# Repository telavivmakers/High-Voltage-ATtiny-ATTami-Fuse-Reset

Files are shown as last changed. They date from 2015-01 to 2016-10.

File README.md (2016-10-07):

## High-Voltage-ATtiny-ATTami-Fuse-Reset

Based on Wayne Holder work "ATTiny Fuse Reset with 12 Volt Charge Pump" from 2010 [link](https://sites.google.com/site/wayneholder/attiny-fuse-reset-with-12-volt-charge-pump) 

With some changes:
* The collector of the Q1 transistor in Waynes diagram shorted D4 to ground via the 4 diods D1, D2, D3 and D4. Even though no harm is expected since the Arduino port pin is short circuit protected it is neater to prevent the short circuit. I moved the collector so it is connected via 1Kohm resistor.
* I changed some of the names in the schematic diagram and in the code to better depict their function.

The circuit will be build as Arduino shield with the following sockets:
* 8 pin DIP socket for 8 pin ATTiny13, ATTiny25, ATTiny45 or ATTiny85 fuse reseting/programming.
* 14 pin DIP socket for 14 pin ATTiny24, ATTiny44 or ATTiny84 fuse reseting/programming.
* Headers and POGO-PIN fixture for reseting/programming [ATTami](https://github.com/telavivmakers/at-tami) boards.

###Schema
[PDF](https://github.com/telavivmakers/High-Voltage-ATtiny-ATTami-Fuse-Reset/raw/master/ATTiny%20Fuse%20Reset%20with%2012V%20Charge%20Pump-schema.pdf)

###Layout
using topoR and some manual work


###BOM 
(Bill_of_materials)
[goog spreadsheet](https://docs.google.com/spreadsheets/d/1eC7mB2Z6gQL06fDRTFxQvt10aQQUTHuxl4aS4G3XxKg/edit?usp=sharing)

###todo
* TARGET/ ISP VCC switch must die
*

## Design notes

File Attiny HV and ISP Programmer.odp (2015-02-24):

## Attiny HV and ISP Programmer

Developed at TAMI

Tel-Aviv Makers International

## Project goals

- Main goal
  - High Voltage fuse reset of ATTami boards.
- By products:
  - High Voltage fuse reset of Attiny components.
  - ISP programming of ATTami boards.
  - ISP programming of Attiny components.
  - ISP programming of various AVR based boards, under either 5V or 3.3V supply.
  - Acceptance test of ATTami boards.
  - Self contained ATTami bootloader loading (Not yet implemented)

ATTami HV and ISP Programmer

2/24/2015

## Project structure

- Arduino shield with the following features:
  - Charge pump circuit to provide the 11.5V for the HV programming.
  - Bi directional 5V to 3.3V level shifters.
  - Sockets to enable programming of ATTami boards and Attiny components.
  - Indicator LEDs.
  - ATTami ATP LEDs.
  - Control switches.

ATTami HV and ISP Programmer

2/24/2015

## Charge pump circuit

- Charge pump is a circuit that produces high voltage by switching of capacitors.
- See: http://en.wikipedia.org/wiki/Charge_pump
- In our case we produce 11.5V out of the Arduino 5V supply.
- The 11.5V is controlled and regulated by the Arduino.

ATTami HV and ISP Programmer

2/24/2015

## Bi directional 5V to 3.3V level shifters

- 4 MOSFET based bi-directional level shifters to shift the 5V Arduino I/O pins level to 3.3V.
- See: http://delphys.net/d.holmes/hardware/levelshift.html

ATTami HV and ISP Programmer

2/24/2015

## Sockets to enable programming of ATTami boards and Attiny components

  - Pogo-Pins socket to enable programming and testing of pinless ATTami boards.
  - Sockets to enable programming and testing of ATTami boards with upper or lower pins.
  - Socket for 8 pin ATtiny programming.
  - Socket for 14 pin ATtiny programming.
  - Socket for 6 pin ISP ribbon.
  - Socket for 10 pin ISP ribbon.

ATTami HV and ISP Programmer

2/24/2015

## Control Switches

- ISP – HV selector: Selects witch programming mode will be performed
- 3.3V – 5V selector: Selects the I/O pins level to conform with the external board connected to the ISP cables.
- ISP Vcc – Target Vcc selector: Selects if The programmer will provide Vcc to the target board via the ISP cables.
- ATTami test pushbutton: Provides Vcc to the ATTami board.
- ATTami load bootloader: Initiate loading to the ATTami of the bootloader Hex file stored on the Arduino Flash memory. (This function is not yet implemented.)

ATTami HV and ISP Programmer

2/24/2015

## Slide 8

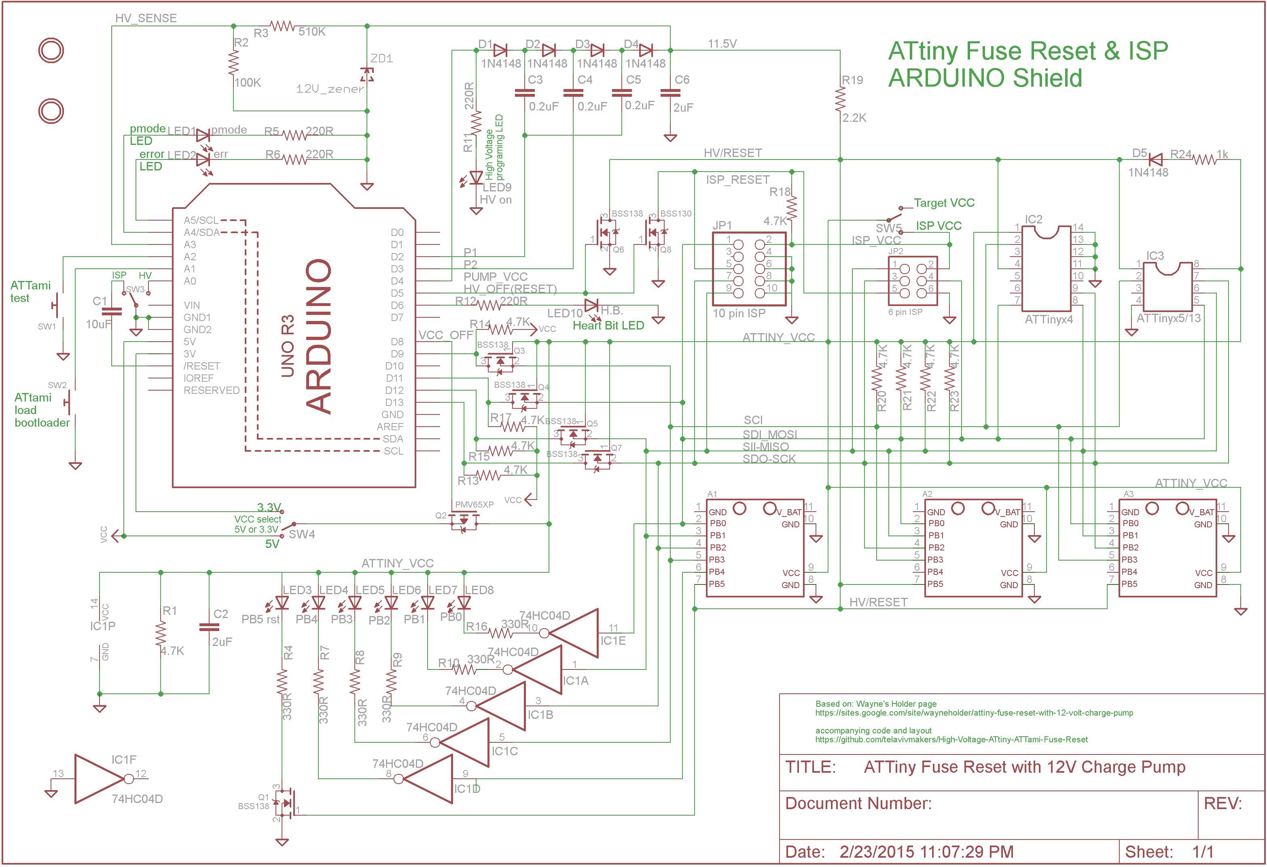
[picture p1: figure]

ATTami HV and ISP Programmer

2/24/2015

## Operation

- There are two modes of operation, each of them runs under different environment:
  - HV fuse reset mode
  - ISP mode
- There are two control buttons. (The control buttons functionality is the same under both modes of operation)
  - ATTami test button
  - ATTAMI load bootloader button

ATTami HV and ISP Programmer

2/24/2015

## Operation cont.

- HV fuse reset mode
  - In this mode you can:
    - Reset the fuses to factory default state.
    - Set the fuses to a predefined state.
    - Define the predefined fuses state.
  - To get into the mode:
    - Connect the Arduino to the PC via a USB cable
    - Set the ISP-HV selector to HV. (HB LED should on)
    - Load Arduino IDE
    - Open the Serial monitor (if necessary set it to 19200 baud rate)
  - To reset the fuses
    - Follow the instructions on the screen menu (While the HV is applied, in options 1 or 2, you should notice a short blink on the HV LED.)

ATTami HV and ISP Programmer

2/24/2015

## Operation cont.

- ISP programming mode
  - In this mode you can:
    - Upload a sketch into the ATtiny.
  - To get into the mode:
    - Connect the Arduino to the PC via a USB cable
    - Set the ISP-HV selector to ISB. (HB LED should pulse)
    - Load Arduino IDE
    - Set the board according to your ATtiny MCU
    - Set programmer to “Arduino as ISP
  - To program the ATtiny
    - Load your sketch into the IDE
    - Click on the “Upload” button. (error LED might blink at start and then turn off, pmode LED should blink while Uploading is performed and then turned off.)

ATTami HV and ISP Programmer

2/24/2015

## Operation cont.

- ATTami test
  - Operates on both HV and ISP modes.
  - On Both modes when not actually programming the ATtiny VCC is off and the reset pin is LOW.
  - When the test pushbutton is pressed Vcc is applied to the ATtiny and the reset pin goes HIGH. (The ATTami, or Attiny, will commence running)
  - Watch the test LEDs for the ATP pattern.

ATTami HV and ISP Programmer

2/24/2015

## Operation cont.

- ATTami load bootloader
  - Operates on both HV and ISP modes.
  - Operates even when the Arduino is not connected to a computer (5V source is nedded)
  - Momentary Push the “ATTami load bootloader” push buton.
  - The Arduino will upload the boot loader Hex file to the ATTami.
- This function is not yet implemented

ATTami HV and ISP Programmer

2/24/2015

## Software build

- The software comprises 3 ino files that are on the same directory
- The directory name is “HV_ISP_programmer”
- The 3 files are: “HV_ISP_programmer.ino”, “ATTinyFuseReset.ino” and “ArduinoISP_ATTami”.
- “HV_ISP_programmer.ino” contains the setup() and loop functions(), “ATTinyFuseReset.ino” contains the HV programming functions, “ArduinoISP_ATTami” contains the ISP functions.
- The IDE compile and build them together and Upload the produced Hex file to the Arduino. You should do it once before using the Programmer.

ATTami HV and ISP Programmer

2/24/2015

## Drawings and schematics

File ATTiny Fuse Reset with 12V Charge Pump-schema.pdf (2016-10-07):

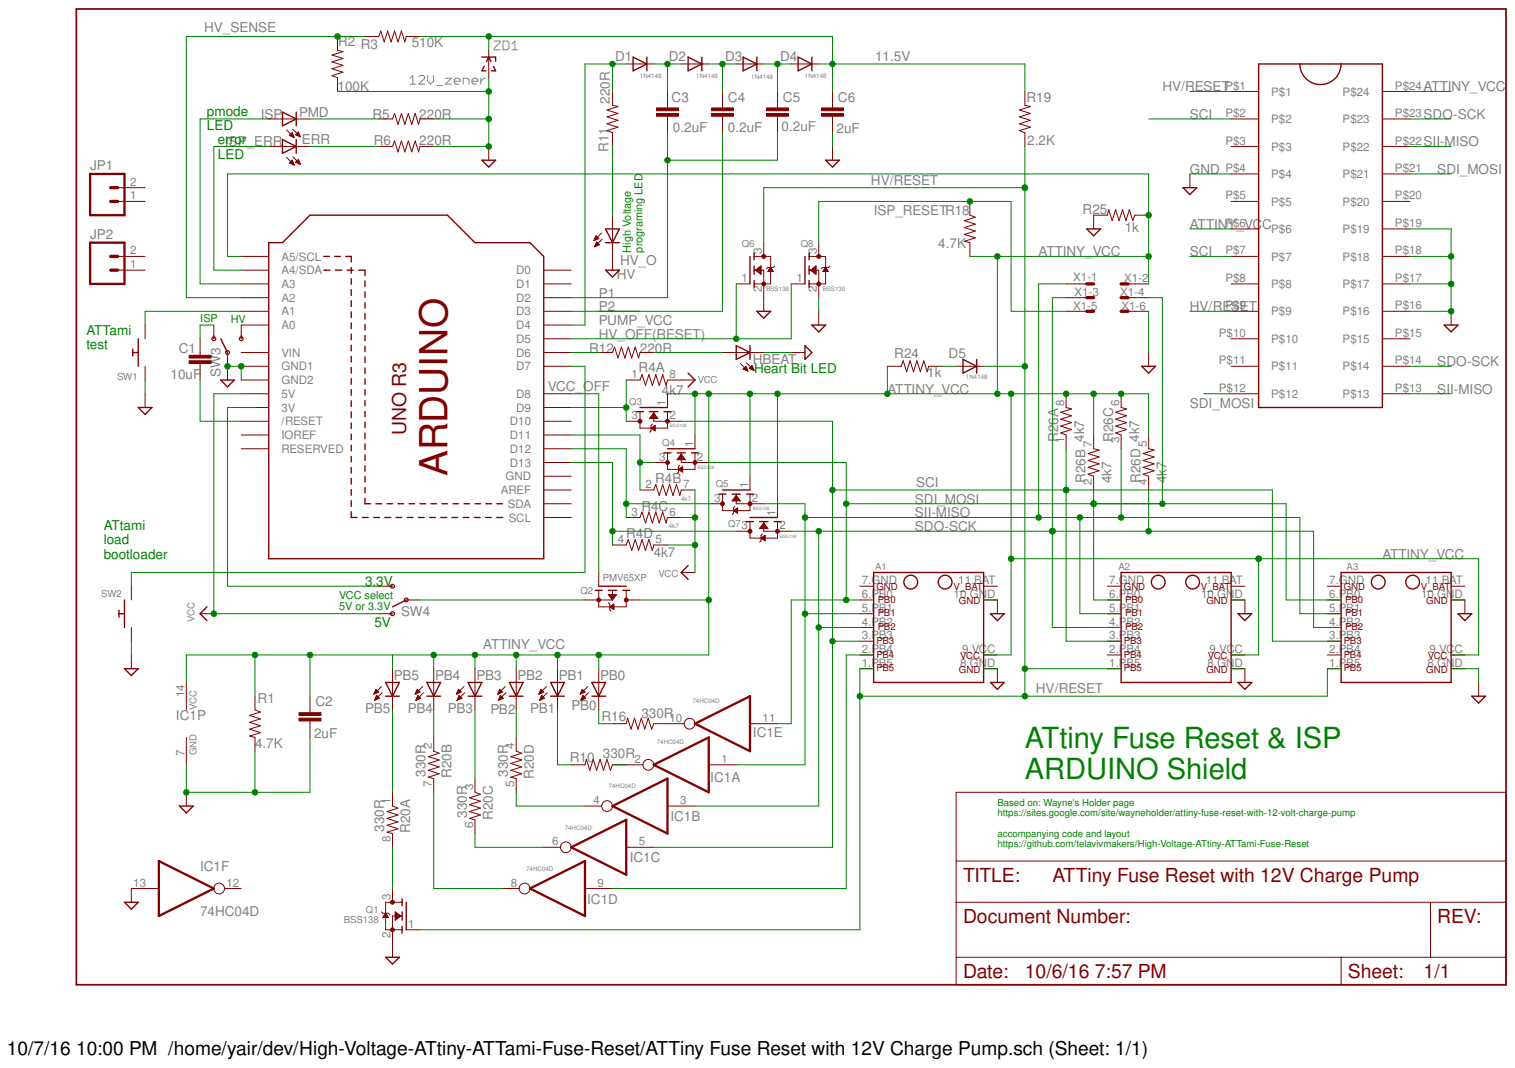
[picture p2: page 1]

SDO-SCK

A3 7.GND
V_BAT VCC ATtiny Fuse Reset & ISP

Based on: Wayne's Holder page
https://sites.google.com/site/wayneholder/attiny-fuse-reset-with-12-volt-charge-pump

accompanying code and layout https://github.com/telavivmakers/High-Voltage-ATtiny-ATTami-Fuse-Reset
TITLE:

ATTiny Fuse Reset with 12V Charge Pump

Document Number: | REV:

Date: 10/6/16 7:57 PM | Sheet: 1/1

10/7/16 10:00 PM /home/yair/dev/High-Voltage-ATtiny-ATTami-Fuse-Reset/ATTiny Fuse Reset with 12V Charge Pump.sch (Sheet: 1/1)

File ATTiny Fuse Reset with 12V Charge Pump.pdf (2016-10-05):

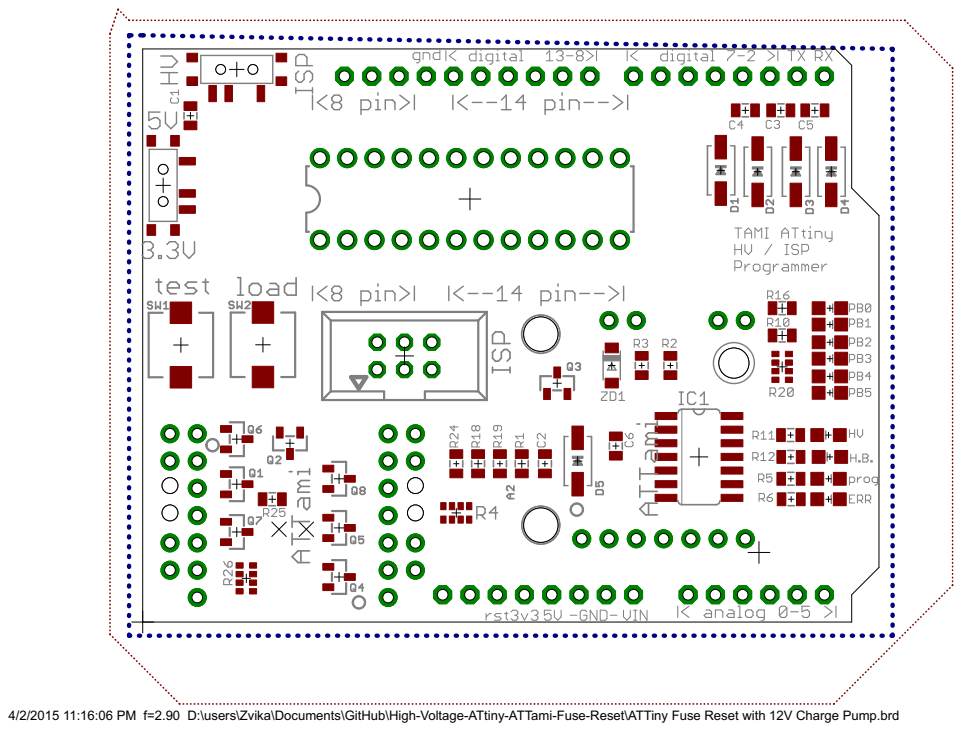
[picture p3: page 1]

4/2/2015 11:16:06 PM f=2.90 D:\users\Zvika\Documents\GitHub\High-Voltage-ATtiny-ATTami-Fuse-Reset\ATTiny Fuse Reset with 12V Charge Pump.brd

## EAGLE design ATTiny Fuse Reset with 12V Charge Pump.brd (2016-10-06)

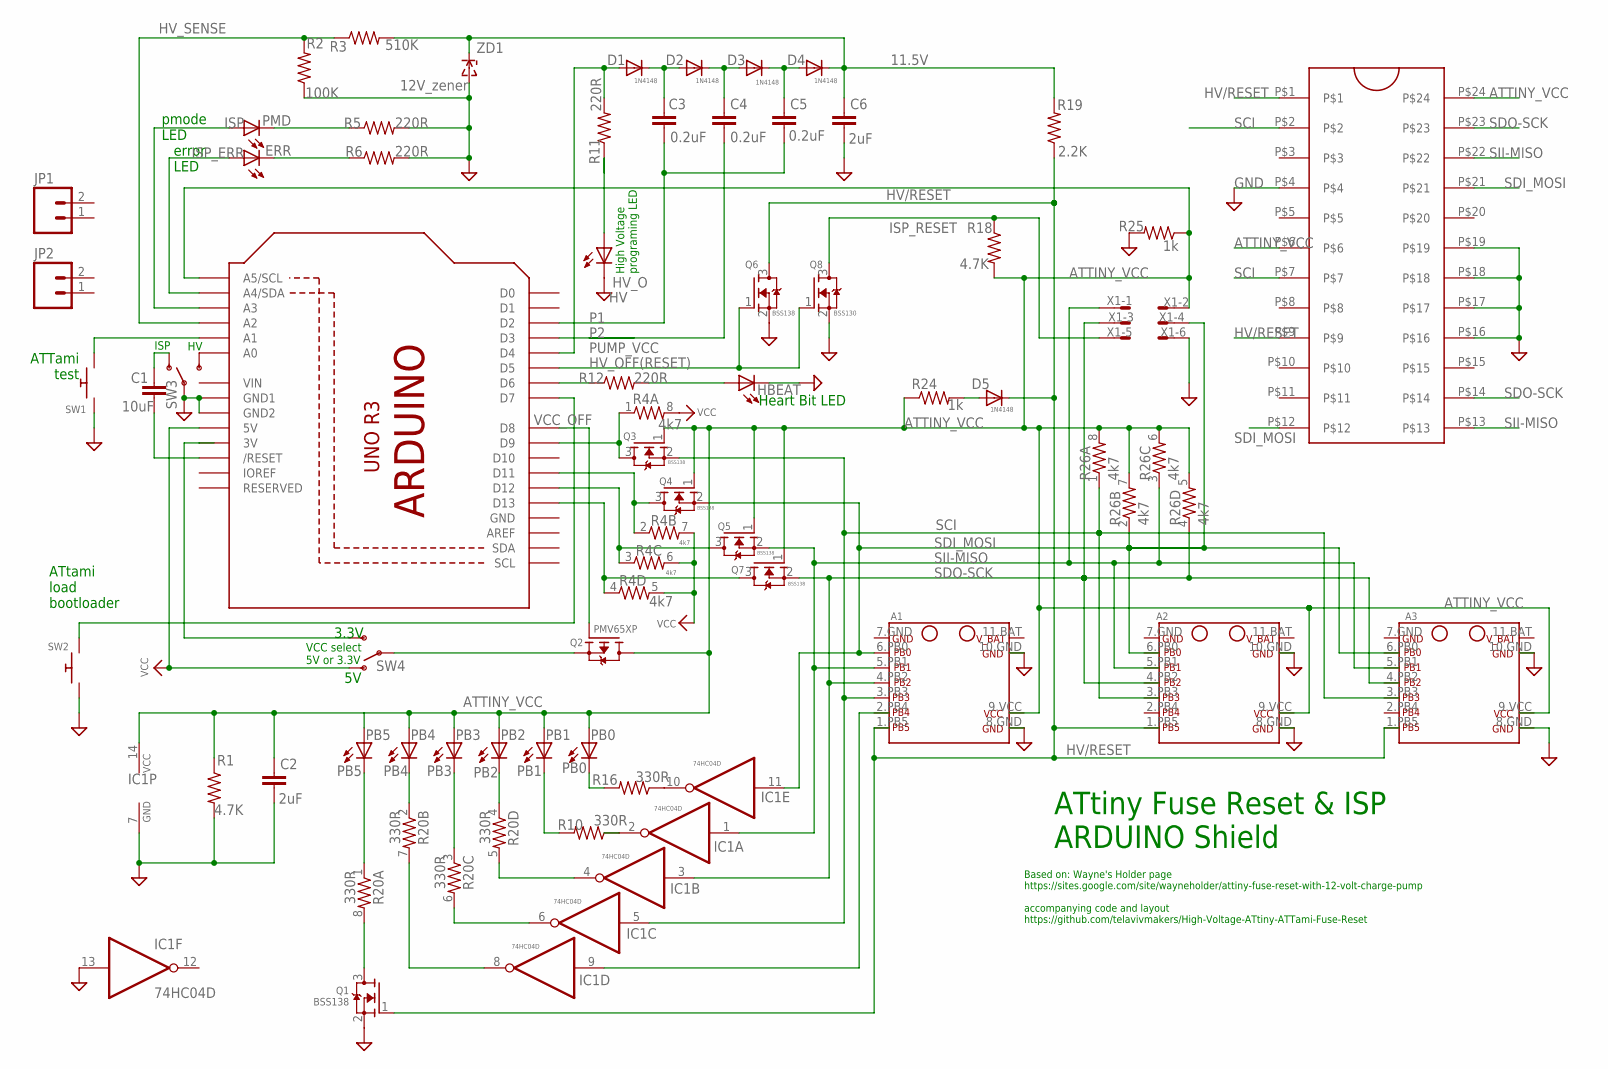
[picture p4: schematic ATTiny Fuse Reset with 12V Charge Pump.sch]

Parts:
A1: ATTami; BREAKOUT_TAMI_NOHOLES
A2: ATTANI_BREAKOUT_PINSHOLES; BREAKOUT_ATTAMI
A3: ATTANI_BREAKOUT_PINSNOHOLE; BREAKOUT_TAMI_NOHOLES
C1: 10uF; 0805
C2, C6: 2uF; 0805
C3, C4, C5: 0.2uF; 0805
D1, D2, D3, D4, D5: 1N4148; SOD-323
HBEAT: H.B.; LED-805
HV_O: HV; LED-805
IC1: 74HC04D; SO14
ISP: PMD; LED-805
ISP_ERR: ERR; LED-805
JP1, JP2: M02POGO_PIN_HOLES_ONLY; 1X02_PP_HOLES_ONLY
PB0: PB0; LED-805
PB1: PB1; LED-805
PB2: PB2; LED-805
PB3: PB3; LED-805
PB4: PB4; LED-805
PB5: PB5; LED-805
Q1, Q3, Q4, Q5, Q6, Q7: BSS138; SOT23-R
Q2: PMV65XP; SOT23-R
Q8: BSS130; SOT23-R
R1, R18: 4.7K; 0805
R2: 100K; 0805
R3: 510K; 0805
R4, R26: 4k7; 0603-ARV
R5, R6, R11, R12: 220R; 0805
R10, R16: 330R; 0805
R19: 2.2K; 0805
R20: 330R; 0603-ARV
R24, R25: 1k; 0805
SW1, SW2: SWITCH_PUSHBUTTONSOFTTOUCHSMD_SJ; PUSHBUTTON_SMD_SJ
SW3, SW4: SWITCH_SPDT; KPS-1290
U1: ARDUINOR3-BPLACE
U$2: ZIFSOCKET-24; DIL-24-ZIF
X1: 057-006-1
ZD1: 12V_zener; SOD-123

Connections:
11.5V: C6.1, D4.CQ (C), R3.2, R19.2, ZD1.C
ATTINY_VCC: A1.9.VCC (VCC), A2.9.VCC (VCC), A3.9.VCC (VCC), C2.1, IC1.14 (VCC), PB0.A, PB1.A, PB2.A, PB3.A, PB4.A, PB5.A, Q2.3 (D), Q3.1 (G), Q4.1 (G), Q5.1 (G), Q7.1 (G), R1.1, R18.2, R24.1, R25.1, R26.5 (2), R26.6 (2), R26.7 (2), R26.8 (2), U1.A5 (A5/SCL), U$2.P$6, U$2.P$24, X1.2
GND: A1.8.GND (GND), A1.10.GND (GND), A2.8.GND (GND), A2.10.GND (GND), A3.8.GND (GND), A3.10.GND (GND), C2.2, C6.2, HBEAT.C, HV_O.C, IC1.7 (GND), IC1.13 (I), Q1.2 (S), Q6.2 (S), Q8.2 (S), R1.2, R2.1, R5.2, R6.2, R25.2, SW1.P$1, SW2.P$1, SW3.P, U1.GND, U1.GND1, U1.GND2, U$2.P$4, U$2.P$16, U$2.P$17, U$2.P$18, U$2.P$19, X1.6, ZD1.A
HV/RESET: A1.1.PB5 (PB5), A2.1.PB5 (PB5), A3.1.PB5 (PB5), D5.CQ (C), Q1.1 (G), Q6.3 (D), R19.1, U$2.P$1, U$2.P$9
HV_OFF(RESET): Q6.1 (G), Q8.1 (G), U1.D5
HV_SENSE: R2.2, R3.1, U1.A2
ISP_RESET: Q8.3 (D), R18.1, X1.5
unnamed: Q2.2 (S), SW4.P
unnamed: Q3.3 (D), R4.1, U1.D9
unnamed: SW3.S, U1.A0
unnamed: HV_O.A, R11.1
unnamed: D5.AQ (A), R24.2
unnamed: ISP.C, R5.1
unnamed: A1.2.PB4 (PB4), IC1.9 (I)
unnamed: Q4.3 (D), R4.2 (1), U1.D11
unnamed: SW1.P$2, U1.A1
unnamed: C3.1, D1.CQ (C), D2.AQ (A)
unnamed: C4.1, D2.CQ (C), D3.AQ (A)
unnamed: C5.1, D3.CQ (C), D4.AQ (A)
unnamed: IC1.10 (O), R16.1
unnamed: C1.1, SW3.O
unnamed: ISP_ERR.C, R6.1
unnamed: SW4.S, U1.3V
unnamed: ISP_ERR.A, U1.A4 (A4/SDA)
unnamed: ISP.A, U1.A3
unnamed: R12.1, U1.D6
unnamed: HBEAT.A, R12.2
unnamed: IC1.2 (O), R10.1
unnamed: SW2.P$2, U1.D7
unnamed: PB2.C, R20.4 (1)
unnamed: IC1.4 (O), R20.5 (2)
unnamed: PB1.C, R10.2
unnamed: IC1.6 (O), R20.6 (2)
unnamed: PB0.C, R16.2
unnamed: IC1.8 (O), R20.7 (2)
unnamed: PB3.C, R20.3 (1)
unnamed: PB4.C, R20.2 (1)
unnamed: PB5.C, R20.1
unnamed: Q1.3 (D), R20.8 (2)
unnamed: C1.2, U1.RESET (/RESET)
unnamed: Q7.3 (D), R4.4 (1), U1.D13
unnamed: Q5.3 (D), R4.3 (1), U1.D12
P1: C3.2, C5.2, U1.D2
P2: C4.2, U1.D3
PUMP_VCC: D1.AQ (A), R11.2, U1.D4
SCI: A2.3.PB3 (PB3), A3.3.PB3 (PB3), IC1.5 (I), Q3.2 (S), R26.1, U$2.P$2, U$2.P$7
SDI_MOSI: A2.6.PB0 (PB0), A3.6.PB0 (PB0), IC1.11 (I), Q4.2 (S), R26.2 (1), U$2.P$12, U$2.P$21, X1.4
SDO-SCK: A2.4.PB2 (PB2), A3.4.PB2 (PB2), IC1.3 (I), Q7.2 (S), R26.4 (1), U$2.P$14, U$2.P$23, X1.3
SII-MISO: A2.5.PB1 (PB1), A3.5.PB1 (PB1), IC1.1 (I), Q5.2 (S), R26.3 (1), U$2.P$13, U$2.P$22
VCC: R4.5 (2), R4.6 (2), R4.7 (2), R4.8 (2), SW4.O, U1.5V
VCC_OFF: Q2.1 (G), U1.D8
VIN: U1.VIN

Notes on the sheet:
ATtiny Fuse Reset & ISP ARDUINO Shield
Based on: Wayne's Holder page https://sites.google.com/site/wayneholder/attiny-fuse-reset-with-12-volt-charge-pump accompanying code and layout https://github.com/telavivmakers/High-Voltage-ATtiny-ATTami-Fuse-Reset
ISP
pmode LED
error LED
Heart Bit LED
High Voltage programing LED
3.3V
ATtami load bootloader
ATTami test
VCC select 5V or 3.3V

Board: 2 copper layers, 59 parts (1 on the bottom side), 51 nets, no tracks yet.

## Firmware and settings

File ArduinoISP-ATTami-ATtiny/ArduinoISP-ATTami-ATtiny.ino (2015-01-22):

// ArduinoISP version 04m3
// Copyright (c) 2008-2011 Randall Bohn
// If you require a license, see 
//     http://www.opensource.org/licenses/bsd-license.php
//
// This sketch turns the Arduino into a AVRISP
// using the following arduino pins:
//
// pin name:    not-mega:         mega(1280 and 2560)
// slave reset: 10:               53 
// MOSI:        11:               51 
// MISO:        12:               50 
// SCK:         13:               52 
//
// Put an LED (with resistor) on the following pins:
// 9: Heartbeat   - shows the programmer is running
// 8: Error       - Lights up if something goes wrong (use red if that makes sense)
// 7: Programming - In communication with the slave
//
// 23 July 2011 Randall Bohn
// -Address Arduino issue 509 :: Portability of ArduinoISP
// http://code.google.com/p/arduino/issues/detail?id=509
//
// October 2010 by Randall Bohn
// - Write to EEPROM > 256 bytes
// - Better use of LEDs:
// -- Flash LED_PMODE on each flash commit
// -- Flash LED_PMODE while writing EEPROM (both give visual feedback of writing progress)
// - Light LED_ERR whenever we hit a STK_NOSYNC. Turn it off when back in sync.
// - Use pins_arduino.h (should also work on Arduino Mega)
//
// October 2009 by David A. Mellis
// - Added support for the read signature command
// 
// February 2009 by Randall Bohn
// - Added support for writing to EEPROM (what took so long?)
// Windows users should consider WinAVR's avrdude instead of the
// avrdude included with Arduino software.
//
// January 2008 by Randall Bohn
// - Thanks to Amplificar for helping me with the STK500 protocol
// - The AVRISP/STK500 (mk I) protocol is used in the arduino bootloader
// - The SPI functions herein were developed for the AVR910_ARD programmer 
// - More information at http://code.google.com/p/mega-isp

#include "pins_arduino.h"
#define RESET     5
#define ATTiny_VCC 8 //target VCC

#define LED_HB    A3//was 9 in the original design. As for now I'm not using the LEDs in the shield
#define LED_ERR   A4//was 8 in the original design.
#define LED_PMODE A5//was 7 in the original design.
#define PROG_FLICKER true

#define HWVER 2
#define SWMAJ 1
#define SWMIN 18

// STK Definitions
#define STK_OK      0x10
#define STK_FAILED  0x11
#define STK_UNKNOWN 0x12
#define STK_INSYNC  0x14
#define STK_NOSYNC  0x15
#define CRC_EOP     0x20 //ok it is a space...

void pulse(int pin, int times);

void setup() {
  Serial.begin(19200);
  pinMode(10, OUTPUT); // Ensures that the built in ATMEGA328 SPI SS would not read the pin as LOW
  digitalWrite(10, HIGH);
  pinMode(ATTiny_VCC, OUTPUT);
  digitalWrite (ATTiny_VCC, HIGH);
  pinMode(LED_PMODE, OUTPUT);
  pulse(LED_PMODE, 2);
  pinMode(LED_ERR, OUTPUT);
  pulse(LED_ERR, 2);
  pinMode(LED_HB, OUTPUT);
  pulse(LED_HB, 2);
}

int error=0;
int pmode=0;
// address for reading and writing, set by 'U' command
int here;
uint8_t buff[256]; // global block storage

#define beget16(addr) (*addr * 256 + *(addr+1) )
typedef struct param {
  uint8_t devicecode;
  uint8_t revision;
  uint8_t progtype;
  uint8_t parmode;
  uint8_t polling;
  uint8_t selftimed;
  uint8_t lockbytes;
  uint8_t fusebytes;
  int flashpoll;
  int eeprompoll;
  int pagesize;
  int eepromsize;
  int flashsize;
} 
parameter;

parameter param;

// this provides a heartbeat on pin 9, so you can tell the software is running.
uint8_t hbval=128;
int8_t hbdelta=8;
void heartbeat() {
  if (hbval > 192) hbdelta = -hbdelta;
  if (hbval < 32) hbdelta = -hbdelta;
  hbval += hbdelta;
  analogWrite(LED_HB, hbval);
  delay(20);
}


void loop(void) {
  // is pmode active?
  if (pmode) digitalWrite(LED_PMODE, HIGH); 
  else digitalWrite(LED_PMODE, LOW);
  // is there an error?
  if (error) digitalWrite(LED_ERR, HIGH); 
  else digitalWrite(LED_ERR, LOW);

  // light the heartbeat LED
  heartbeat();
  if (Serial.available()) {
    avrisp();
  }
}

uint8_t getch() {
  while(!Serial.available());
  return Serial.read();
}
void fill(int n) {
  for (int x = 0; x < n; x++) {
    buff[x] = getch();
  }
}

#define PTIME 30
void pulse(int pin, int times) {
  do {
    digitalWrite(pin, HIGH);
    delay(PTIME);
    digitalWrite(pin, LOW);
    delay(PTIME);
  } 
  while (times--);
}

void prog_lamp(int state) {
  if (PROG_FLICKER)
    digitalWrite(LED_PMODE, state);
}

void spi_init() {
  uint8_t x;
  SPCR = 0x53;
  x=SPSR;
  x=SPDR;
}

void spi_wait() {
  do {
  } 
  while (!(SPSR & (1 << SPIF)));
}

uint8_t spi_send(uint8_t b) {
  uint8_t reply;
  SPDR=b;
  spi_wait();
  reply = SPDR;
  return reply;
}

uint8_t spi_transaction(uint8_t a, uint8_t b, uint8_t c, uint8_t d) {
  uint8_t n;
  spi_send(a); 
  n=spi_send(b);
  //if (n != a) error = -1;
  n=spi_send(c);
  return spi_send(d);
}

void empty_reply() {
  if (CRC_EOP == getch()) {
    Serial.print((char)STK_INSYNC);
    Serial.print((char)STK_OK);
  } 
  else {
    error++;
    Serial.print((char)STK_NOSYNC);
  }
}

void breply(uint8_t b) {
  if (CRC_EOP == getch()) {
    Serial.print((char)STK_INSYNC);
    Serial.print((char)b);
    Serial.print((char)STK_OK);
  } 
  else {
    error++;
    Serial.print((char)STK_NOSYNC);
  }
}

void get_version(uint8_t c) {
  switch(c) {
  case 0x80:
    breply(HWVER);
    break;
  case 0x81:
    breply(SWMAJ);
    break;
  case 0x82:
    breply(SWMIN);
    break;
  case 0x93:
    breply('S'); // serial programmer
    break;
  default:
    breply(0);
  }
}

void set_parameters() {
  // call this after reading paramter packet into buff[]
  param.devicecode = buff[0];
  param.revision   = buff[1];
  param.progtype   = buff[2];
  param.parmode    = buff[3];
  param.polling    = buff[4];
  param.selftimed  = buff[5];
  param.lockbytes  = buff[6];
  param.fusebytes  = buff[7];
  param.flashpoll  = buff[8]; 
  // ignore buff[9] (= buff[8])
  // following are 16 bits (big endian)
  param.eeprompoll = beget16(&buff[10]);
  param.pagesize   = beget16(&buff[12]);
  param.eepromsize = beget16(&buff[14]);

  // 32 bits flashsize (big endian)
  param.flashsize = buff[16] * 0x01000000
    + buff[17] * 0x00010000
    + buff[18] * 0x00000100
    + buff[19];

}

void start_pmode() {
  spi_init();
  // following delays may not work on all targets...
  pinMode(RESET, OUTPUT);
//  digitalWrite(RESET, HIGH); //original
  digitalWrite(RESET, LOW); //modified
  pinMode(SCK, OUTPUT);
  digitalWrite(SCK, LOW);
  delay(50);
//  digitalWrite(RESET, LOW); //original
  digitalWrite(RESET, HIGH); //modified
  delay(50);
  pinMode(MISO, INPUT);
  pinMode(MOSI, OUTPUT);
  spi_transaction(0xAC, 0x53, 0x00, 0x00);
  pmode = 1;
}

void end_pmode() {
  pinMode(MISO, INPUT);
  pinMode(MOSI, INPUT);
  pinMode(SCK, INPUT);
  pinMode(RESET, INPUT);
  pmode = 0;
}

void universal() {
  int w;
  uint8_t ch;

  fill(4);
  ch = spi_transaction(buff[0], buff[1], buff[2], buff[3]);
  breply(ch);
}

void flash(uint8_t hilo, int addr, uint8_t data) {
  spi_transaction(0x40+8*hilo, 
  addr>>8 & 0xFF, 
  addr & 0xFF,
  data);
}
void commit(int addr) {
  if (PROG_FLICKER) prog_lamp(LOW);
  spi_transaction(0x4C, (addr >> 8) & 0xFF, addr & 0xFF, 0);
  if (PROG_FLICKER) {
    delay(PTIME);
    prog_lamp(HIGH);
  }
}

//#define _current_page(x) (here & 0xFFFFE0)
int current_page(int addr) {
  if (param.pagesize == 32)  return here & 0xFFFFFFF0;
  if (param.pagesize == 64)  return here & 0xFFFFFFE0;
  if (param.pagesize == 128) return here & 0xFFFFFFC0;
  if (param.pagesize == 256) return here & 0xFFFFFF80;
  return here;
}


void write_flash(int length) {
  fill(length);
  if (CRC_EOP == getch()) {
    Serial.print((char) STK_INSYNC);
    Serial.print((char) write_flash_pages(length));
  } 
  else {
    error++;
    Serial.print((char) STK_NOSYNC);
  }
}

uint8_t write_flash_pages(int length) {
  int x = 0;
  int page = current_page(here);
  while (x < length) {
    if (page != current_page(here)) {
      commit(page);
      page = current_page(here);
    }
    flash(LOW, here, buff[x++]);
    flash(HIGH, here, buff[x++]);
    here++;
  }

  commit(page);

  return STK_OK;
}

#define EECHUNK (32)
uint8_t write_eeprom(int length) {
  // here is a word address, get the byte address
  int start = here * 2;
  int remaining = length;
  if (length > param.eepromsize) {
    error++;
    return STK_FAILED;
  }
  while (remaining > EECHUNK) {
    write_eeprom_chunk(start, EECHUNK);
    start += EECHUNK;
    remaining -= EECHUNK;
  }
  write_eeprom_chunk(start, remaining);
  return STK_OK;
}
// write (length) bytes, (start) is a byte address
uint8_t write_eeprom_chunk(int start, int length) {
  // this writes byte-by-byte,
  // page writing may be faster (4 bytes at a time)
  fill(length);
  prog_lamp(LOW);
  for (int x = 0; x < length; x++) {
    int addr = start+x;
    spi_transaction(0xC0, (addr>>8) & 0xFF, addr & 0xFF, buff[x]);
    delay(45);
  }
  prog_lamp(HIGH); 
  return STK_OK;
}

void program_page() {
  char result = (char) STK_FAILED;
  int length = 256 * getch();
  length += getch();
  char memtype = getch();
  // flash memory @here, (length) bytes
  if (memtype == 'F') {
    write_flash(length);
    return;
  }
  if (memtype == 'E') {
    result = (char)write_eeprom(length);
    if (CRC_EOP == getch()) {
      Serial.print((char) STK_INSYNC);
      Serial.print(result);
    } 
    else {
      error++;
      Serial.print((char) STK_NOSYNC);
    }
    return;
  }
  Serial.print((char)STK_FAILED);
  return;
}

uint8_t flash_read(uint8_t hilo, int addr) {
  return spi_transaction(0x20 + hilo * 8,
  (addr >> 8) & 0xFF,
  addr & 0xFF,
  0);
}

char flash_read_page(int length) {
  for (int x = 0; x < length; x+=2) {
    uint8_t low = flash_read(LOW, here);
    Serial.print((char) low);
    uint8_t high = flash_read(HIGH, here);
    Serial.print((char) high);
    here++;
  }
  return STK_OK;
}

char eeprom_read_page(int length) {
  // here again we have a word address
  int start = here * 2;
  for (int x = 0; x < length; x++) {
    int addr = start + x;
    uint8_t ee = spi_transaction(0xA0, (addr >> 8) & 0xFF, addr & 0xFF, 0xFF);
    Serial.print((char) ee);
  }
  return STK_OK;
}

void read_page() {
  char result = (char)STK_FAILED;
  int length = 256 * getch();
  length += getch();
  char memtype = getch();
  if (CRC_EOP != getch()) {
    error++;
    Serial.print((char) STK_NOSYNC);
    return;
  }
  Serial.print((char) STK_INSYNC);
  if (memtype == 'F') result = flash_read_page(length);
  if (memtype == 'E') result = eeprom_read_page(length);
  Serial.print(result);
  return;
}

void read_signature() {
  if (CRC_EOP != getch()) {
    error++;
    Serial.print((char) STK_NOSYNC);
    return;
  }
  Serial.print((char) STK_INSYNC);
  uint8_t high = spi_transaction(0x30, 0x00, 0x00, 0x00);
  Serial.print((char) high);
  uint8_t middle = spi_transaction(0x30, 0x00, 0x01, 0x00);
  Serial.print((char) middle);
  uint8_t low = spi_transaction(0x30, 0x00, 0x02, 0x00);
  Serial.print((char) low);
  Serial.print((char) STK_OK);
}
//////////////////////////////////////////
//////////////////////////////////////////


////////////////////////////////////
////////////////////////////////////
int avrisp() { 
  uint8_t data, low, high;
  uint8_t ch = getch();
  switch (ch) {
  case '0': // signon
    error = 0;
    empty_reply();
    break;
  case '1':
    if (getch() == CRC_EOP) {
      Serial.print((char) STK_INSYNC);
      Serial.print("AVR ISP");
      Serial.print((char) STK_OK);
    }
    break;
  case 'A':
    get_version(getch());
    break;
  case 'B':
    fill(20);
    set_parameters();
    empty_reply();
    break;
  case 'E': // extended parameters - ignore for now
    fill(5);
    empty_reply();
    break;

  case 'P':
    start_pmode();
    empty_reply();
    break;
  case 'U': // set address (word)
    here = getch();
    here += 256 * getch();
    empty_reply();
    break;

  case 0x60: //STK_PROG_FLASH
    low = getch();
    high = getch();
    empty_reply();
    break;
  case 0x61: //STK_PROG_DATA
    data = getch();
    empty_reply();
    break;

  case 0x64: //STK_PROG_PAGE
    program_page();
    break;

  case 0x74: //STK_READ_PAGE 't'
    read_page();    
    break;

  case 'V': //0x56
    universal();
    break;
  case 'Q': //0x51
    error=0;
    end_pmode();
    empty_reply();
    break;

  case 0x75: //STK_READ_SIGN 'u'
    read_signature();
    break;

    // expecting a command, not CRC_EOP
    // this is how we can get back in sync
  case CRC_EOP:
    error++;
    Serial.print((char) STK_NOSYNC);
    break;

    // anything else we will return STK_UNKNOWN
  default:
    error++;
    if (CRC_EOP == getch()) 
      Serial.print((char)STK_UNKNOWN);
    else
      Serial.print((char)STK_NOSYNC);
  }
}

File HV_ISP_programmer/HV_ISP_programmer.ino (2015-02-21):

#include <TimerOne.h>

#define ATtiny_VCC      8		//target VCC
#define LED_HB		6		//Yellow LED, was 9 in the original design. As for now I'm not using the LEDs in the shield
#define HV_ISP_select   A0	        //HV ISP toggle switch
#define ATTami_test     A1		//check if ATTami test push button is pressed.
#define ATTami_bootloader A2            //check if ATTami load bootloader push button is pressed.
#define HV_sense	A3		// Analog read of a sample of the 11.5V produced by the charge pump circuit
#define LED_PMODE	A4		//Green LED, was 7 in the original design.
#define LED_ERR		A5		//Red LED, was 8 in the original design.
#define RESET		5		// pin 5 is also reffered to as HV_off in "ATTinyFuseReset" file
#define SCI		9		// D9, Target Clock
#define SDO		13		// D13, Target Data Output
#define SII		12		// D12, Target Instruction Input
#define SDI		11		// D11,  Target Data Input

byte switches_old; //keeps the old position of HV_ISP_select, ATTami_test and ATTami_bootloader switches
byte switches_new; //keeps the new position of HV_ISP_select, ATTami_test and ATTami_bootloader switches

void setup() {
  Serial.begin(19200);
  pinMode(10, OUTPUT); // Ensures that the built in ATMEGA328 SPI SS would not read the pin as LOW
  digitalWrite(10, HIGH);
  pinMode(ATtiny_VCC, OUTPUT);
  //The following 3 LEDs are used in ISP mode only
  pinMode(LED_HB, OUTPUT);
  pinMode(LED_PMODE, OUTPUT);
  pinMode(LED_ERR, OUTPUT);
  Timer1.initialize(500);
  Timer1.attachInterrupt(ticker);
  //The following pins are used by the HV programmer in "ATTinyFuseReset" file.
  pinMode (A1, OUTPUT); // used to toggle A1 output pin on every pass through the loop in the ISR (or ticker) routine on "ATTinyFuseReset" file. It should be removed in the final version.
  pinMode(SDI, OUTPUT);
  pinMode(SII, OUTPUT);
  pinMode(SCI, OUTPUT);
  pinMode(SDO, OUTPUT);     // Will be configured as INPUT when in "ArduinoISP_ATTami" file
  analogReference(DEFAULT);
  pinMode (RESET, OUTPUT);
  digitalWrite(HV_ISP_select, HIGH); //activates the "HV_ISP_select" pin pullUp resistor.
  digitalWrite(ATTami_test, HIGH); //activates the "ATTami_test" pin pullUp resistor.
  digitalWrite(ATTami_bootloader, HIGH); //activates the "ATTami_bootloader" pin pullUp resistor.
}

void loop(){
  for (int i=0; i<=50; i++){
    switches_new = PINC & B00000111;
    if (switches_new != switches_old) i=0;
    switches_old = switches_new;
    delay (1);
  }
  if ((switches_new & B00000110) == B00000110){ // no push button is pressed
    if (switches_new & B00000001) { // ISP mode
      TIMSK1 &= ~1<<TOIE1; //disable 12V pump, see: ticker() function in "ATTinyFuseReset" file
      pinMode(LED_HB, OUTPUT);
      pinMode(LED_PMODE, OUTPUT);
      pinMode(LED_ERR, OUTPUT);
      pulse(LED_HB, 2);
      pulse(LED_PMODE, 2);
      pulse(LED_ERR, 2);
      Serial.println("\nGoing into ISP mode");
      Serial.println("Under Tools/Board menu choose the appropriate ATTiny device");
      Serial.println("Under Tools/Programmer menu choose Arduino as ISP");
      Serial.println("and Upload your sketch");
      ISPloop();
    }
    else { // HV mode
      TIMSK1 |= 1<<TOIE1; //enable 12V pump, see: ticker() function in "ATTinyFuseReset" file
      digitalWrite (ATtiny_VCC, LOW);
      digitalWrite(LED_HB, HIGH);
      HVloop();
    }
  }
  else{ // one of the push buttons is pressed
    TIMSK1 &= ~1<<TOIE1; //disable 12V pump, see: ticker() function in "ATTinyFuseReset" file
    if (switches_new & B00000010){    //ATTAmi test
      Serial.println("\nGoing into ATTiny test mode");
      ATTami_test_mode(); 
    }
    else if (switches_new & B00000100){ //ATTAmi load bootloader
      Serial.println("ATTami load bootloader");
      ATTami_load_bootloader();
    }
  }
} 

void ATTami_test_mode(){
  TIMSK1 &= ~1<<TOIE1; //disable 12V pump, see: ticker() function in "ATTinyFuseReset" file
  digitalWrite (LED_HB, LOW);
  digitalWrite(ATtiny_VCC, HIGH);
  digitalWrite(RESET, LOW);
  while (switches_new == (PINC & B00000111));
  digitalWrite(ATtiny_VCC, LOW);
  digitalWrite(RESET, HIGH);
}

void ATTami_load_bootloader(){
  Serial.println("Yet not implemented.");
}

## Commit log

2015-01-13 schematic base version
    [ATTiny Fuse Reset with 12V Charge Pump.sch]
2015-01-14 version with dip8 and dip14
    [ATTiny Fuse Reset with 12V Charge Pump.brd]
2015-01-14 need to add ISP header
    [ATTiny Fuse Reset with 12V Charge Pump.brd, ATTiny Fuse Reset with 12V Charge Pump.sch]
2015-01-15 added 1N4148 value
    [ATTiny Fuse Reset with 12V Charge Pump.brd, ATTiny Fuse Reset with 12V Charge Pump.sch]
2015-01-16 some caretaking
    [ATTiny Fuse Reset with 12V Charge Pump.brd, ATTiny Fuse Reset with 12V Charge Pump.sch]
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2015-01-18 started library of parts
    [ATTiny Fuse Reset with 12V Charge Pump.brd, ATTiny Fuse Reset with 12V Charge Pump.sch]
2015-01-18 Added 12V protecting Zener
    [ATTiny Fuse Reset with 12V Charge Pump.brd, ATTiny Fuse Reset with 12V Charge Pump.sch]
2015-01-18 Some cosmetic changes
    [ATTiny Fuse Reset with 12V Charge Pump.brd, ATTiny Fuse Reset with 12V Charge Pump.sch]
2015-01-19 layout and package of attami added
    [ATTiny Fuse Reset with 12V Charge Pump.brd, ATTiny Fuse Reset with 12V Charge Pump.sch]
2015-01-19 Mirroring one of the ATTami packages
    [ATTiny Fuse Reset with 12V Charge Pump.brd, ATTiny Fuse Reset with 12V Charge Pump.sch]
2015-01-19 Changes in the schematic
    MOSI, MISO, SCK and 12V_OFF are now connected to the correct pins of the
    Arduino UNO
    [ATTiny Fuse Reset with 12V Charge Pump.brd, ATTiny Fuse Reset with 12V Charge Pump.sch]
2015-01-19 error correction: ATTINY_VCC wire was not connected
    [ATTiny Fuse Reset with 12V Charge Pump.brd, ATTiny Fuse Reset with 12V Charge Pump.sch]
2015-01-19 Some more corrections
    [ATTiny Fuse Reset with 12V Charge Pump.brd, ATTiny Fuse Reset with 12V Charge Pump.sch]
2015-01-19 Updating the sketch
    Updating the sketch to comply with the updated schematic
    For the time being the sketch only deal with ATTiny fuses reset.
    Next step will be adding ISP capability.
    [ATTinyFuseReset3.ino]
2015-01-20 R6, R10 and R11 values changed
    [ATTiny Fuse Reset with 12V Charge Pump.brd, ATTiny Fuse Reset with 12V Charge Pump.sch]
2015-01-20 combining HV reset with ISP slave select
    [ATTiny Fuse Reset with 12V Charge Pump.brd, ATTiny Fuse Reset with 12V Charge Pump.sch]
2015-01-21 Revert "combining HV reset with ISP slave select"
    This reverts commit 8866a214dde31db0049427def42afcfb88113351.
    [ATTiny Fuse Reset with 12V Charge Pump.brd, ATTiny Fuse Reset with 12V Charge Pump.sch]
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2015-01-24 Changes in the schematic
    [ATTiny Fuse Reset with 12V Charge Pump.brd, ATTiny Fuse Reset with 12V Charge Pump.sch]
2015-01-24 changed attiny breakout size
    [ATTiny Fuse Reset with 12V Charge Pump.brd, ATTiny Fuse Reset with 12V Charge Pump.sch]
2015-01-24 ATTami components connected
    [ATTiny Fuse Reset with 12V Charge Pump.brd, ATTiny Fuse Reset with 12V Charge Pump.sch]
2015-01-25 Added 3 LEDs. The LEDs indicate activity and error
    [ATTiny Fuse Reset with 12V Charge Pump.brd, ATTiny Fuse Reset with 12V Charge Pump.sch]
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2015-01-26 removed values, kept names
    need to move throuhole compenents from above the usb connector
    [ATTiny Fuse Reset with 12V Charge Pump.brd, ATTiny Fuse Reset with 12V Charge Pump.sch]
2015-02-10 Added features
    1. Ability to program 5V or 3.3V devices.
    2. ATTami acceptance test.
    3. Uploading of ATTami bootloader directly from ARDUINO memory.
    [ATTiny Fuse Reset with 12V Charge Pump.brd, ATTiny Fuse Reset with 12V Charge Pump.sch]
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2015-02-11 Isolate the +12V from the ISP sockets
    3 N channel MOS-FET transistors are used in order to isolate the +12V
    from components which are not supposed to get high voltage
    [ATTiny Fuse Reset with 12V Charge Pump.brd, ATTiny Fuse Reset with 12V Charge Pump.sch]
2015-02-11 added prefix and ran renumber ULP, also cosmetics on schema
    [ATTiny Fuse Reset with 12V Charge Pump.brd, ATTiny Fuse Reset with 12V Charge Pump.sch]
2015-02-12 Reshuffle Arduino I/O pins. New look for the "ATTAMI_BREAKOUT_SHEILD"
    At this stage the software is not consistent with the new Arduino pin
    arrangement. It will be fixed soon.
    [ATTiny Fuse Reset with 12V Charge Pump.brd, ATTiny Fuse Reset with 12V Charge Pump.sch]
2015-02-13 Added four N channel MOS-FET bidirectional 3.3 to 5 V level shifters
    [ATTiny Fuse Reset with 12V Charge Pump.brd, ATTiny Fuse Reset with 12V Charge Pump.sch]
2015-02-14 Same diagram, better arranged.
    [ATTiny Fuse Reset with 12V Charge Pump.brd, ATTiny Fuse Reset with 12V Charge Pump.sch]
2015-02-22 Parts renumber and partial placement attempt
    [ATTiny Fuse Reset with 12V Charge Pump.brd, ATTiny Fuse Reset with 12V Charge Pump.sch]
2015-02-24 Schematic and board layout improvment
    [ATTiny Fuse Reset with 12V Charge Pump.brd, ATTiny Fuse Reset with 12V Charge Pump.sch]
2015-02-27 "TARGET/ ISP VCC switch"-B-Gone
    [ATTiny Fuse Reset with 12V Charge Pump.brd, ATTiny Fuse Reset with 12V Charge Pump.sch]
2015-03-02 added array resistors, moved transistor under attami
    [ATTiny Fuse Reset with 12V Charge Pump.brd, ATTiny Fuse Reset with 12V Charge Pump.sch]
2015-03-02 zif inside, aded to lib, removed 10 pin ISP
    [ATTiny Fuse Reset with 12V Charge Pump.brd, ATTiny Fuse Reset with 12V Charge Pump.sch]
2015-03-02 added clean arduino board, replaced attami with new parts from the lib
    [ATTiny Fuse Reset with 12V Charge Pump.brd, ATTiny Fuse Reset with 12V Charge Pump.sch]
2015-03-02 zif24 ito brd
    [ATTiny Fuse Reset with 12V Charge Pump.brd, ATTiny Fuse Reset with 12V Charge Pump.sch]
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2015-03-09 removed pins from silkscreen on arduino device
    [ATTiny Fuse Reset with 12V Charge Pump.brd, ATTiny Fuse Reset with 12V Charge Pump.sch]
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2015-03-16 bit order and removed unsued layers
    [ATTiny Fuse Reset with 12V Charge Pump.brd]
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2015-03-17 more routing, now switching for topoR
    [ATTiny Fuse Reset with 12V Charge Pump.brd]
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2015-03-17 aligned xtra pins overlayed on attami device
    [ATTiny Fuse Reset with 12V Charge Pump.brd, ATTiny Fuse Reset with 12V Charge Pump.sch]
2015-03-18 topoR first effort, not bad
    [ATTiny Fuse Reset with 12V Charge Pump.brd]
2015-03-26 branch to fix issues with borked master
    [ATTiny Fuse Reset with 12V Charge Pump.brd, ATTiny Fuse Reset with 12V Charge Pump_2136-88sa_2139-98sa.brd]
2015-03-26 issues fixed
    the two pins are connected now.
    the Vin issue is ignored (actually this pin is an output of the Arduino)
    [ATTiny Fuse Reset with 12V Charge Pump.brd, ATTiny Fuse Reset with 12V Charge Pump.sch]
2015-03-28 ordered name layer with silkscreen. to silkscreen use tNames,tPlaces, tDocu, Names layers
    [ATTiny Fuse Reset with 12V Charge Pump.brd]
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2015-08-04 added 4layer version, WIP
    [ATTiny Fuse Reset with 12V Charge Pump.brd, ATTiny Fuse Reset with 12V Charge Pump_2136-88sa_2139-98sa.brd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]
2015-08-05 new brd with 4layer
    [ASSEMBLY_BOTTOM.gbr, ASSEMBLY_BOTTOM_ASSY.gbr, ASSEMBLY_TOP.gbr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]
2015-08-05 new brd with 4layer, tnames fix
    [ATTiny Fuse Reset with 12V Charge Pump.GBL, ATTiny Fuse Reset with 12V Charge Pump.GBO, ATTiny Fuse Reset with 12V Charge Pump.GBP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]
2015-08-06 fixied traces in 4layer board, version in board-topor go to fab
    [ATTiny Fuse Reset with 12V Charge Pump.brd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]
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2016-09-22 fab caniudate from topoR
    [ATTiny Fuse Reset with 12V Charge Pump - 4layer.brd, ATTiny Fuse Reset with 12V Charge Pump.brd, ATTiny Fuse Reset with 12V Charge Pump_2271-94sa_2472-29sa.brd]
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2016-10-06 got corrct brd/sch from fixing_issue branch
    [ATTiny Fuse Reset with 12V Charge Pump.brd, ATTiny Fuse Reset with 12V Charge Pump.sch]
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

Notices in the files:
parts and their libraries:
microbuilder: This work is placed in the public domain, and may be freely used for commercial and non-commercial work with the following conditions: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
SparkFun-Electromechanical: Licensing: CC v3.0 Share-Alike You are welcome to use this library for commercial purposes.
